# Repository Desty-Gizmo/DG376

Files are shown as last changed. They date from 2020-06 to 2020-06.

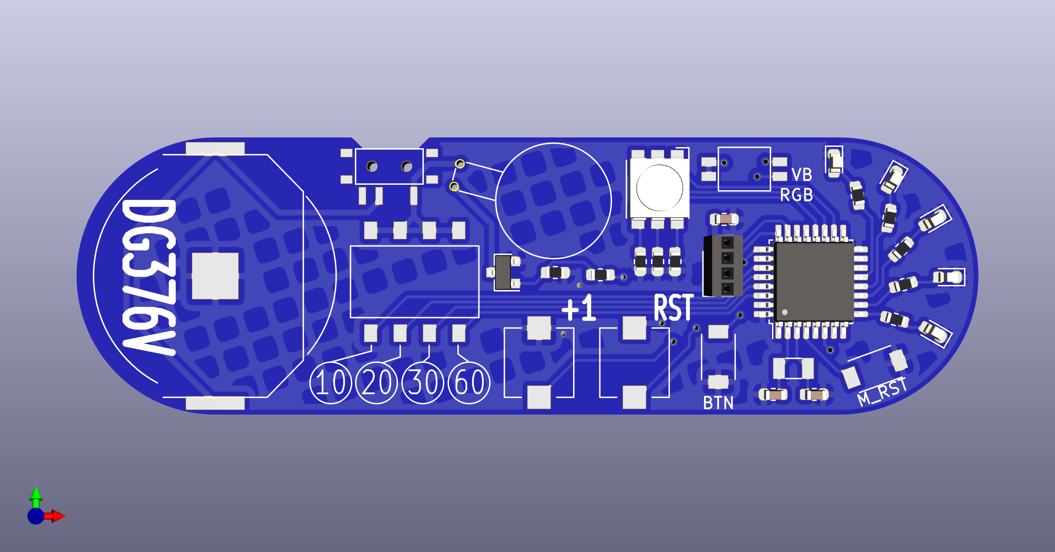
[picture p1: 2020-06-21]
Hardware/DG376_KiCad_F.png

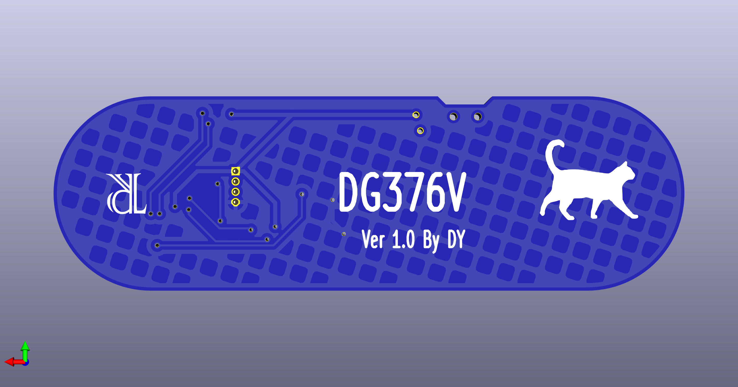
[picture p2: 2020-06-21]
Hardware/DG376_KiCad_B.png

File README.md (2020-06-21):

# DG376

DG means "Desty Gizmo" or "Desty Gadget", a series of low power gadgets.

376: a random number I assign to name the model.

DG376V: using 10mm disk vibration motor (through-hole).
DG376R: using biased weight vibration motor (SMD).

# Counter

A counter that supports quick countdown function. Will notify the user when the time is up.

# MCU

STM32L010C6T6 $1.70 -> $1.67.  
STM32L011K4T6 $1.79 -> $1.68. Has symbol in KiCad

# Note

- Set GPIO to float before sleep.
-

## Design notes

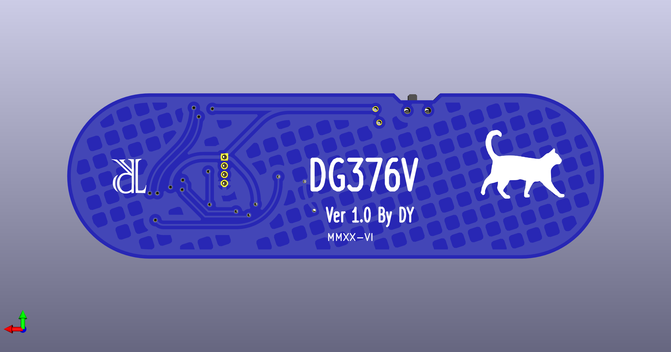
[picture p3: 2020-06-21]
Hardware/DG376_KiCad_B_2.png

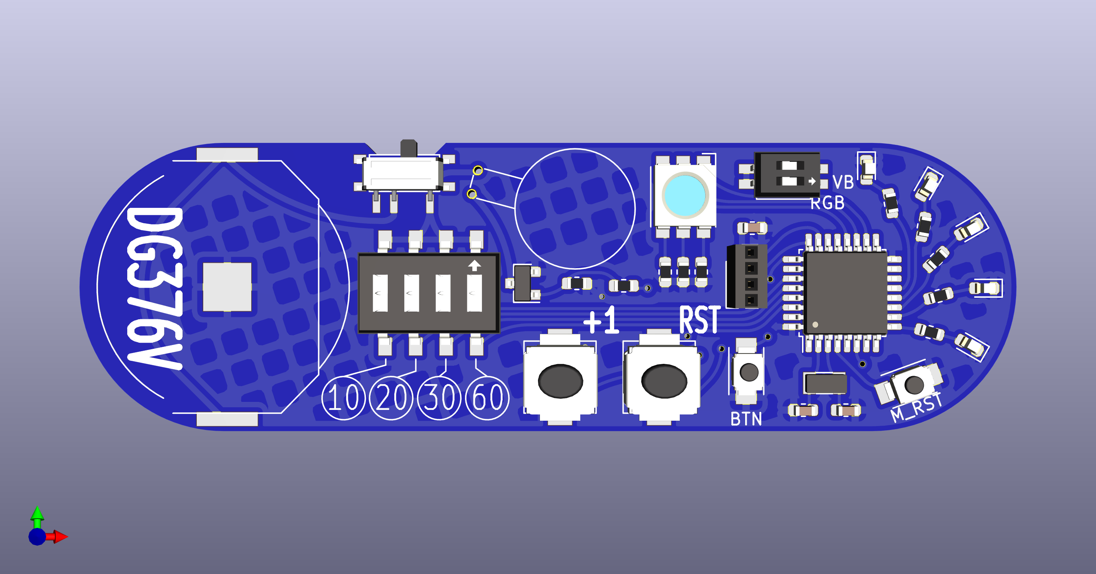
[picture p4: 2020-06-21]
Hardware/DG376_KiCad_F_2.png

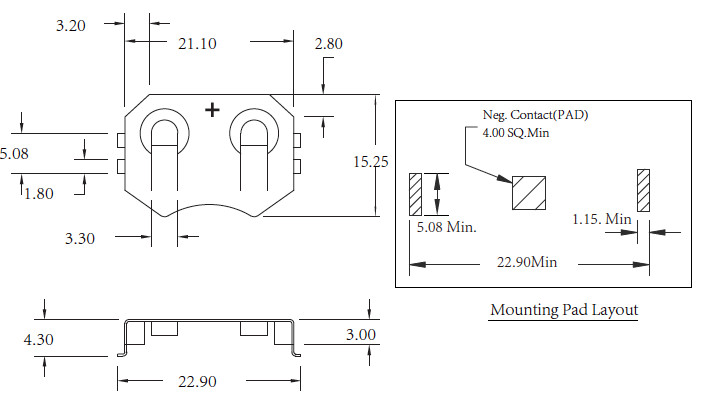
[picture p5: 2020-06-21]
Datasheet/CR2032 Battery Holder.jpg

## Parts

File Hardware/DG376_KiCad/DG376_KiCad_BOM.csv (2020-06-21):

Source: | /Users/dlyang/Dropbox/Project/2020.DG376-Counter/Hardware/DG376_KiCad/DG376_KiCad.kicad_sch
Date: | Friday, June 05, 2020 at 02:58:03 PM
Tool: | Eeschema (5.99.0-1734-g575ad7128)
Generator: | /private/var/folders/nt/y2zl667d17z2_5mz2jj_qz8r0000gn/T/AppTranslocation/0FF80091-CBEB-471F-9E27-5001AB55A9E2/d/kicad.app/Contents/SharedSupport/plugins/bom_csv_grouped_by_value.py
Component Count: | 32
Individual Components:
Item | Qty | Reference(s) | Value | LibPart | Footprint | Datasheet
 |  | BT1 | CR2032 | Device:Battery_Cell | LTD_Customized:CR2032_Battery_Holder | ~
 |  | C1 | 12pF | Device:C_Small | Capacitor_SMD:C_0603_1608Metric | ~
 |  | C2 | 12pF | Device:C_Small | Capacitor_SMD:C_0603_1608Metric | ~
 |  | C3 | 10nF | Device:C_Small | Capacitor_SMD:C_0603_1608Metric | ~
 |  | D1 | RGB_LED_5050 | DLY_Customized:RGB_LED_5050 | LED_SMD:LED_RGB_5050-6
 |  | D2 | LED | Device:LED | LED_SMD:LED_0603_1608Metric | ~
 |  | D3 | LED | Device:LED | LED_SMD:LED_0603_1608Metric | ~
 |  | D4 | LED | Device:LED | LED_SMD:LED_0603_1608Metric | ~
 |  | D5 | LED | Device:LED | LED_SMD:LED_0603_1608Metric | ~
 |  | D6 | LED | Device:LED | LED_SMD:LED_0603_1608Metric | ~
 |  | J1 | Conn_01x04 | Connector_Generic:Conn_01x04 | Connector_PinSocket_1.27mm:PinSocket_1x04_P1.27mm_Vertical | ~
 |  | M1 | Motor_DC | Motor:Motor_DC | LTD_Customized:Vibration Motor 10mm | ~
 |  | Q1 | MMBT3904 | Transistor_BJT:MMBT3904 | Package_TO_SOT_SMD:SOT-23 | https://www.fairchildsemi.com/datasheets/2N/2N3904.pdf
 |  | R3 | 2.2k | Device:R | Resistor_SMD:R_0603_1608Metric | ~
 |  | R4 | 2.2k | Device:R | Resistor_SMD:R_0603_1608Metric | ~
 |  | R5 | 2.2k | Device:R | Resistor_SMD:R_0603_1608Metric | ~
 |  | R6 | 2.2k | Device:R | Resistor_SMD:R_0603_1608Metric | ~
 |  | R7 | 2.2k | Device:R | Resistor_SMD:R_0603_1608Metric | ~
 |  | R8 | 2.2k | Device:R | Resistor_SMD:R_0603_1608Metric | ~
 |  | R9 | 2.2k | Device:R | Resistor_SMD:R_0603_1608Metric | ~
 |  | R10 | 2.2k | Device:R | Resistor_SMD:R_0603_1608Metric | ~
 |  | R11 | 4.7k | Device:R | Resistor_SMD:R_0603_1608Metric | ~
 |  | R12 | 47k | Device:R | Resistor_SMD:R_0603_1608Metric | ~
 |  | SW1 | PWR_SW | Switch:SW_SPDT | LTD_Customized:Shouhan MSK12C02 | ~
 |  | SW2 | CNT_START | Switch:SW_Push | LTD_Customized:Alps_SMD_Button_SKPMAPE010 | ~
 |  | SW3 | T_SELECT | Switch:SW_DIP_x04 | LTD_Customized:Diptronics DMR-04-V-TR | ~
 |  | SW4 | CNT_RST | Switch:SW_Push | LTD_Customized:Alps_SMD_Button_SKPMAPE010 | ~
 |  | SW5 | MCU_RST | Switch:SW_Push | LTD_Customized:USAKRO UK-B0273-SP25Y | ~
 |  | SW6 | USR_BTN | Switch:SW_Push | LTD_Customized:USAKRO UK-B0273-SP25Y | ~
 |  | SW7 | SW_DIP_x02 | Switch:SW_DIP_x02 | LTD_Customized:Diptronics_SW_DIP_DHN-02-V-T-R | ~
 |  | U1 | STM32L011K4Tx | MCU_ST_STM32L0:STM32L011K4Tx | Package_QFP:LQFP-32_7x7mm_P0.8mm | http://www.st.com/st-web-ui/static/active/en/resource/technical/document/datasheet/DM00206508.pdf
 |  | Y1 | 32.768Hz_OSC | Device:Crystal | Crystal:Crystal_SMD_3215-2Pin_3.2x1.5mm | ~
Collated Components:
Item | Qty | Reference(s) | Value | LibPart | Footprint | Datasheet
1 | 1 | BT1 | CR2032 | Device:Battery_Cell | LTD_Customized:CR2032_Battery_Holder | ~
2 | 2 | C1, C2 | 12pF | Device:C_Small | Capacitor_SMD:C_0603_1608Metric | ~
3 | 1 | C3 | 10nF | Device:C_Small | Capacitor_SMD:C_0603_1608Metric | ~
4 | 1 | D1 | RGB_LED_5050 | DLY_Customized:RGB_LED_5050 | LED_SMD:LED_RGB_5050-6
5 | 5 | D2, D3, D4, D5, D6 | LED | Device:LED | LED_SMD:LED_0603_1608Metric | ~
6 | 1 | J1 | Conn_01x04 | Connector_Generic:Conn_01x04 | Connector_PinSocket_1.27mm:PinSocket_1x04_P1.27mm_Vertical | ~
7 | 1 | M1 | Motor_DC | Motor:Motor_DC | LTD_Customized:Vibration Motor 10mm | ~
8 | 1 | Q1 | MMBT3904 | Transistor_BJT:MMBT3904 | Package_TO_SOT_SMD:SOT-23 | https://www.fairchildsemi.com/datasheets/2N/2N3904.pdf
9 | 8 | R3, R4, R5, R6, R7, R8, R9, R10 | 2.2k | Device:R | Resistor_SMD:R_0603_1608Metric | ~
10 | 1 | R11 | 4.7k | Device:R | Resistor_SMD:R_0603_1608Metric | ~
11 | 1 | R12 | 47k | Device:R | Resistor_SMD:R_0603_1608Metric | ~
12 | 1 | SW1 | PWR_SW | Switch:SW_SPDT | LTD_Customized:Shouhan MSK12C02 | ~
13 | 1 | SW2 | CNT_START | Switch:SW_Push | LTD_Customized:Alps_SMD_Button_SKPMAPE010 | ~
14 | 1 | SW3 | T_SELECT | Switch:SW_DIP_x04 | LTD_Customized:Diptronics DMR-04-V-TR | ~
15 | 1 | SW4 | CNT_RST | Switch:SW_Push | LTD_Customized:Alps_SMD_Button_SKPMAPE010 | ~
16 | 1 | SW5 | MCU_RST | Switch:SW_Push | LTD_Customized:USAKRO UK-B0273-SP25Y | ~
17 | 1 | SW6 | USR_BTN | Switch:SW_Push | LTD_Customized:USAKRO UK-B0273-SP25Y | ~
18 | 1 | SW7 | SW_DIP_x02 | Switch:SW_DIP_x02 | LTD_Customized:Diptronics_SW_DIP_DHN-02-V-T-R | ~
19 | 1 | U1 | STM32L011K4Tx | MCU_ST_STM32L0:STM32L011K4Tx | Package_QFP:LQFP-32_7x7mm_P0.8mm | http://www.st.com/st-web-ui/static/active/en/resource/technical/document/datasheet/DM00206508.pdf
20 | 1 | Y1 | 32.768Hz_OSC | Device:Crystal | Crystal:Crystal_SMD_3215-2Pin_3.2x1.5mm | ~

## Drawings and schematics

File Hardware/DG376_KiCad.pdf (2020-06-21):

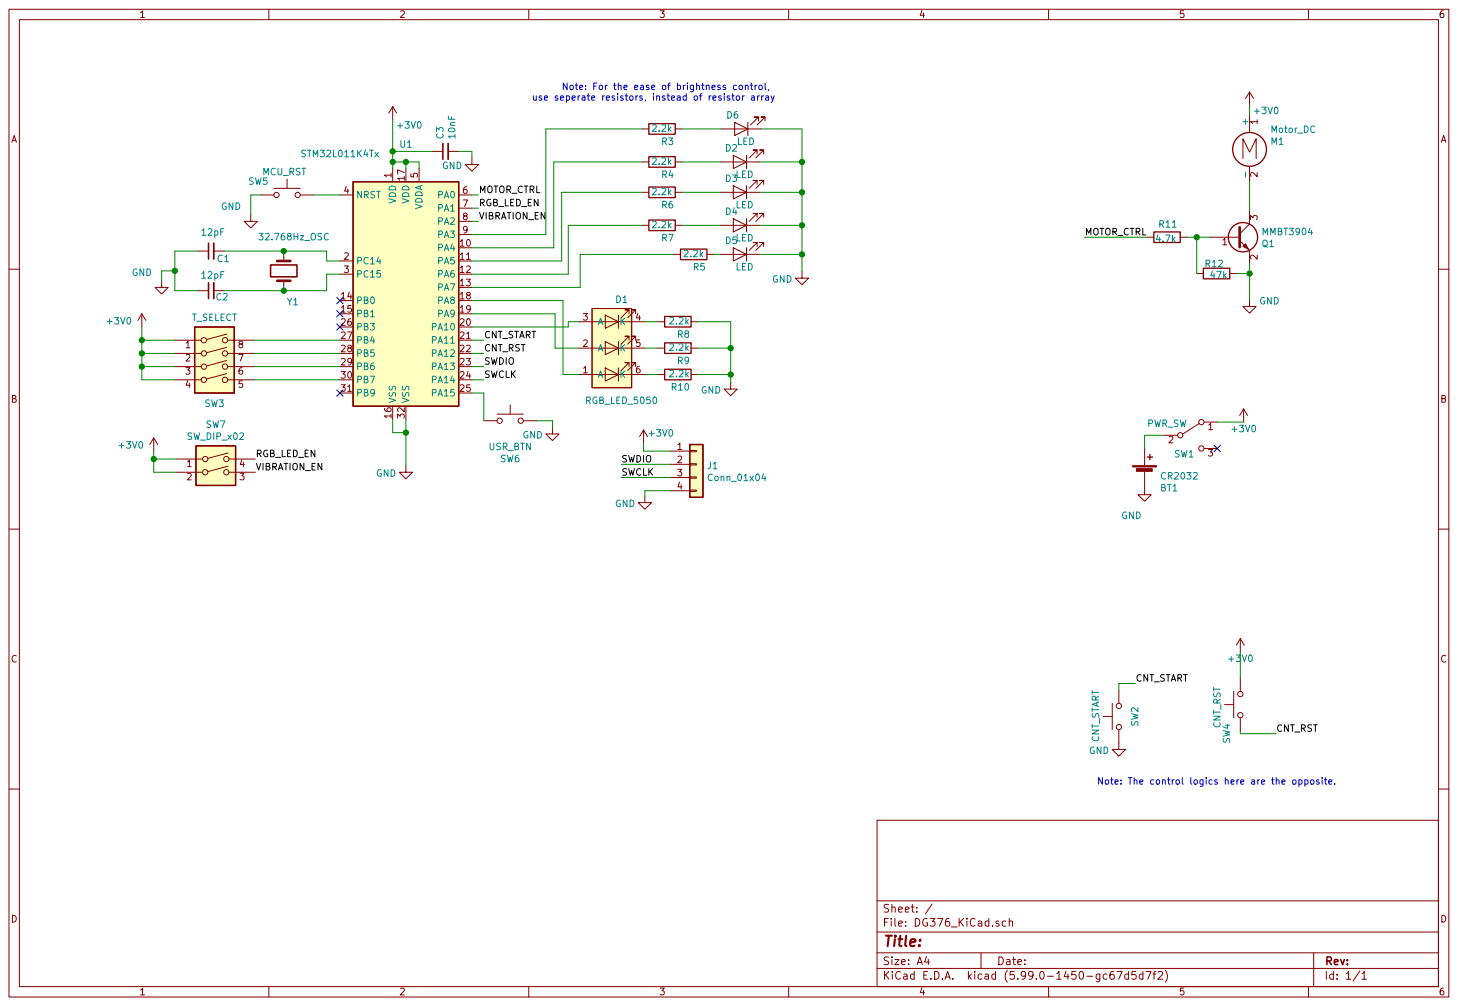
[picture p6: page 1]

SWCLK Note: For the ease of brightness control,
use seperate resistors, instead of resistor array
RGB_LED_EN MOTOR_CTRL SWCLK

Note: The control logics here are the opposite.

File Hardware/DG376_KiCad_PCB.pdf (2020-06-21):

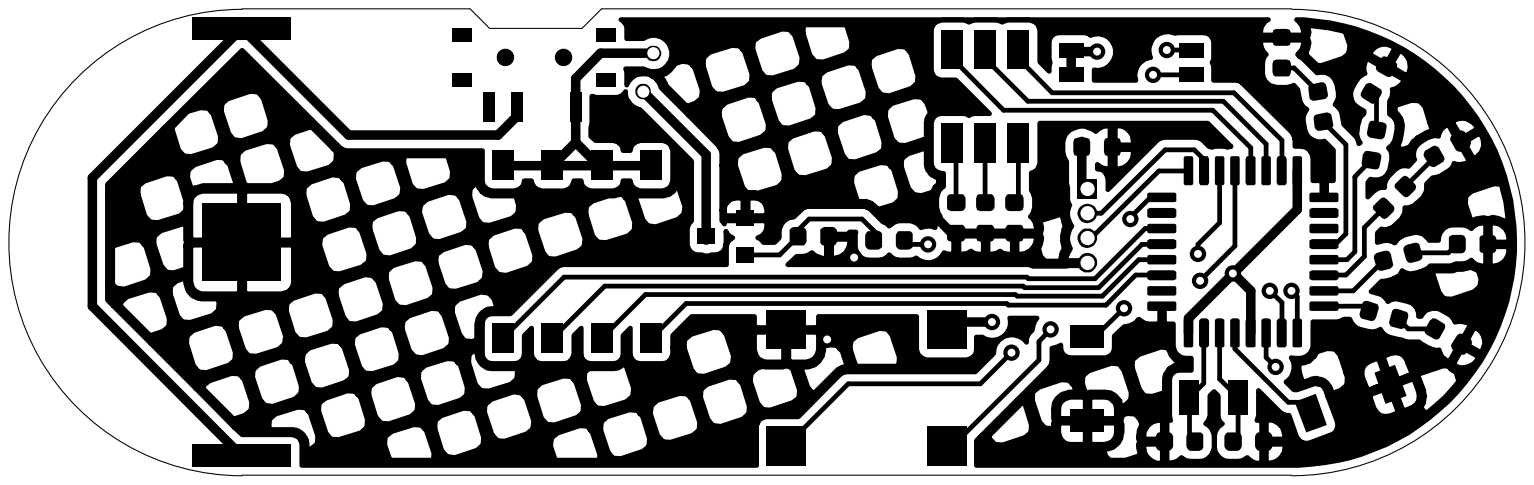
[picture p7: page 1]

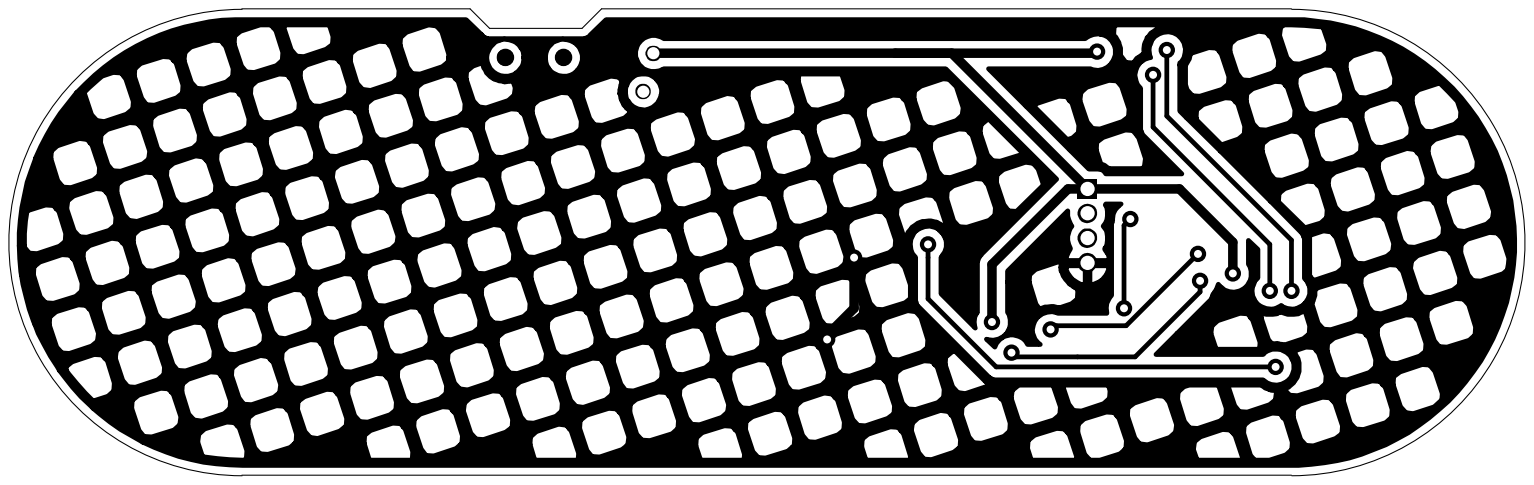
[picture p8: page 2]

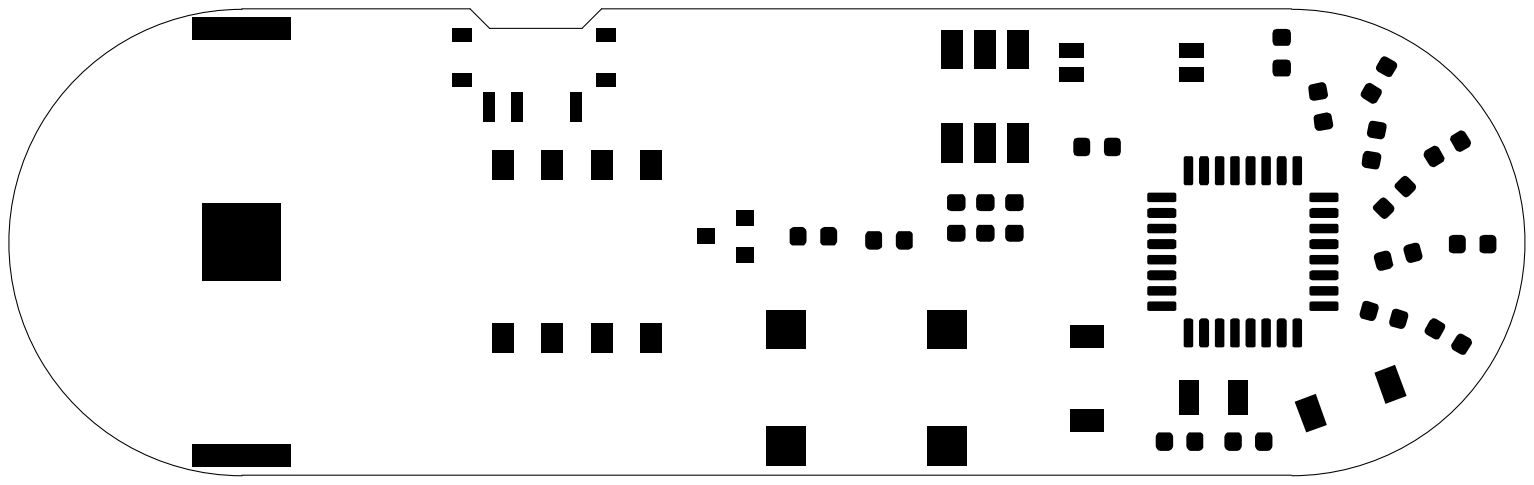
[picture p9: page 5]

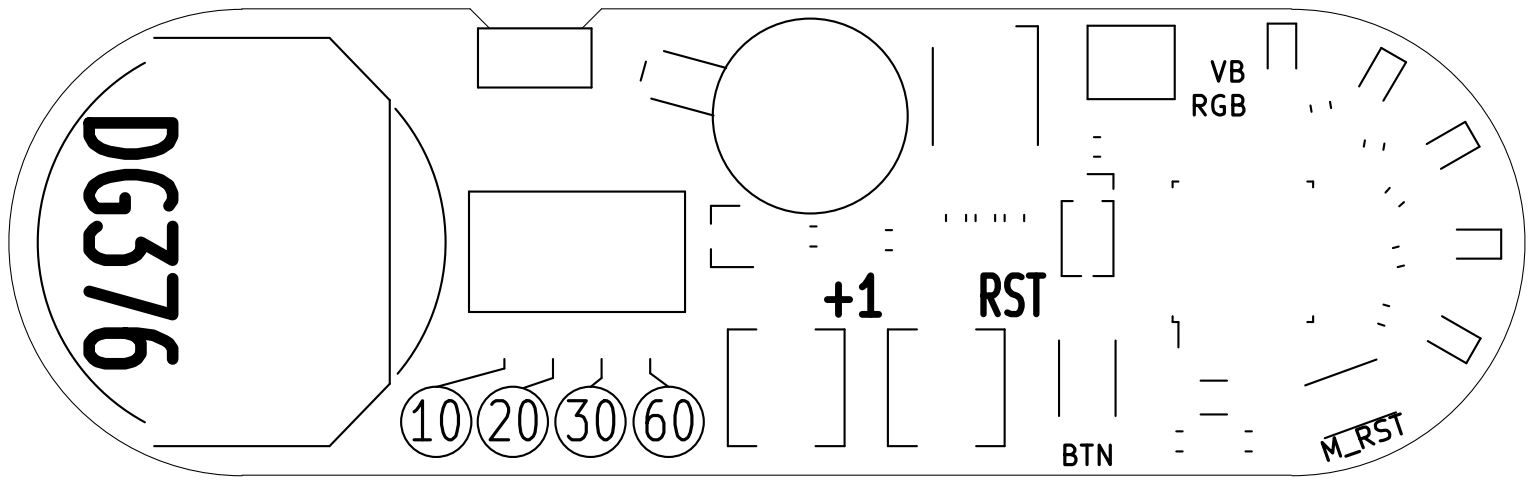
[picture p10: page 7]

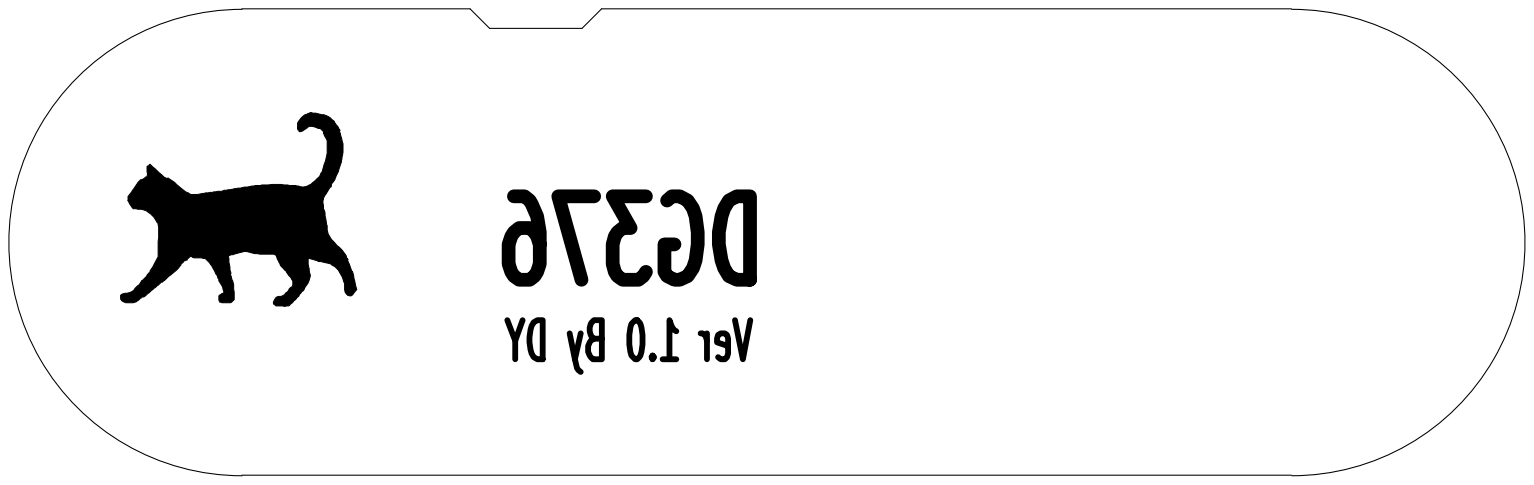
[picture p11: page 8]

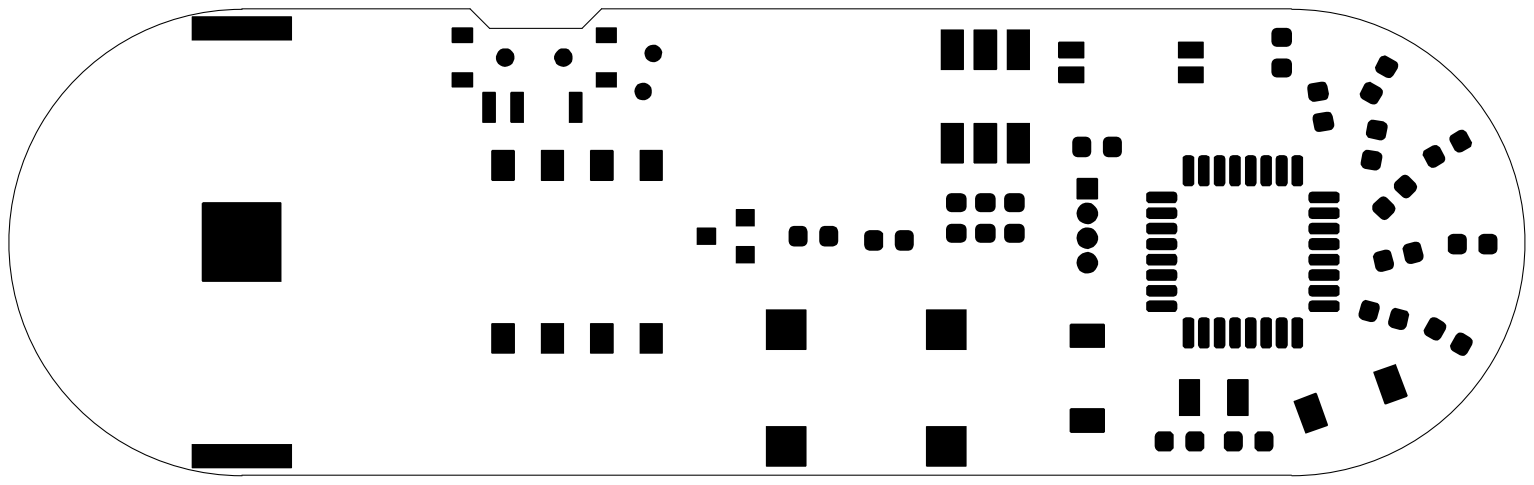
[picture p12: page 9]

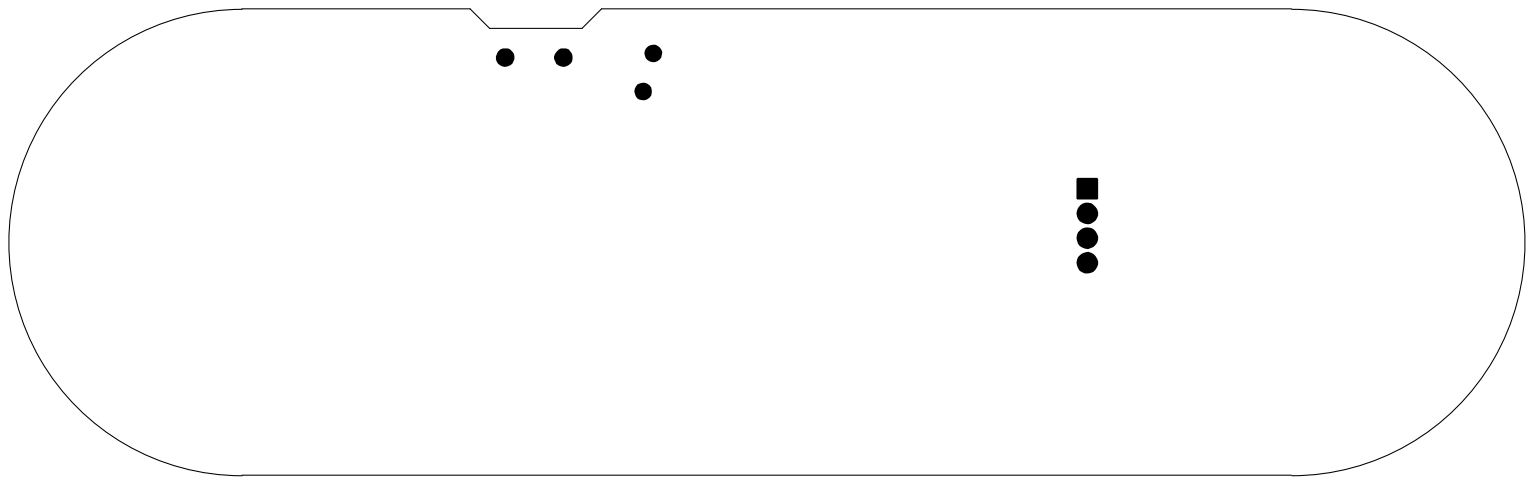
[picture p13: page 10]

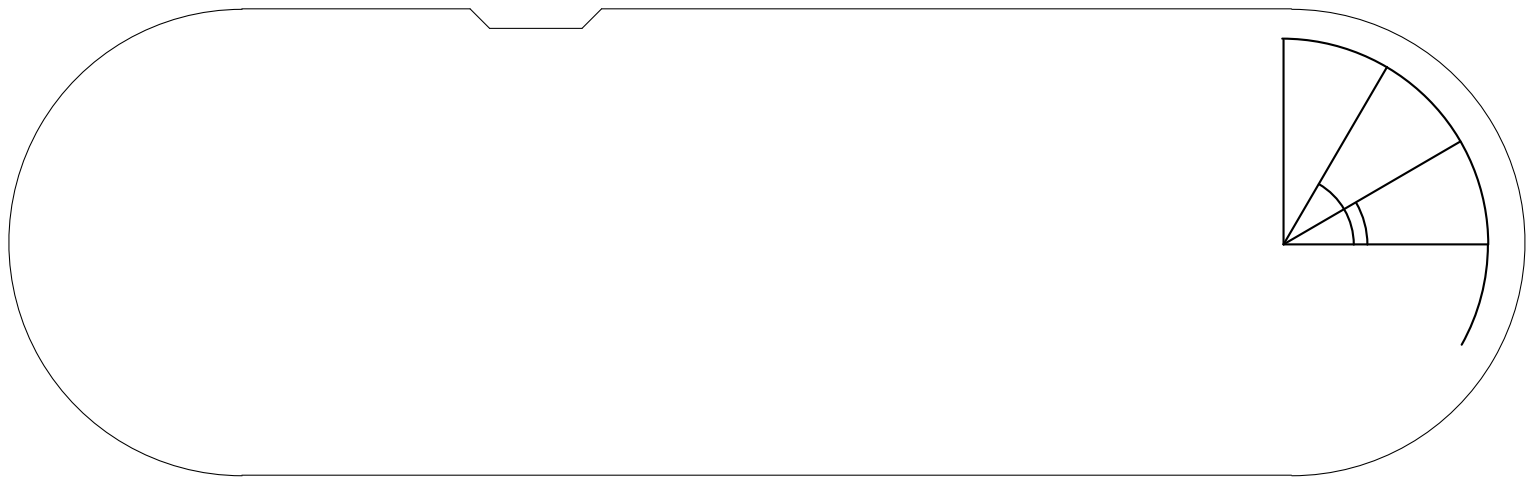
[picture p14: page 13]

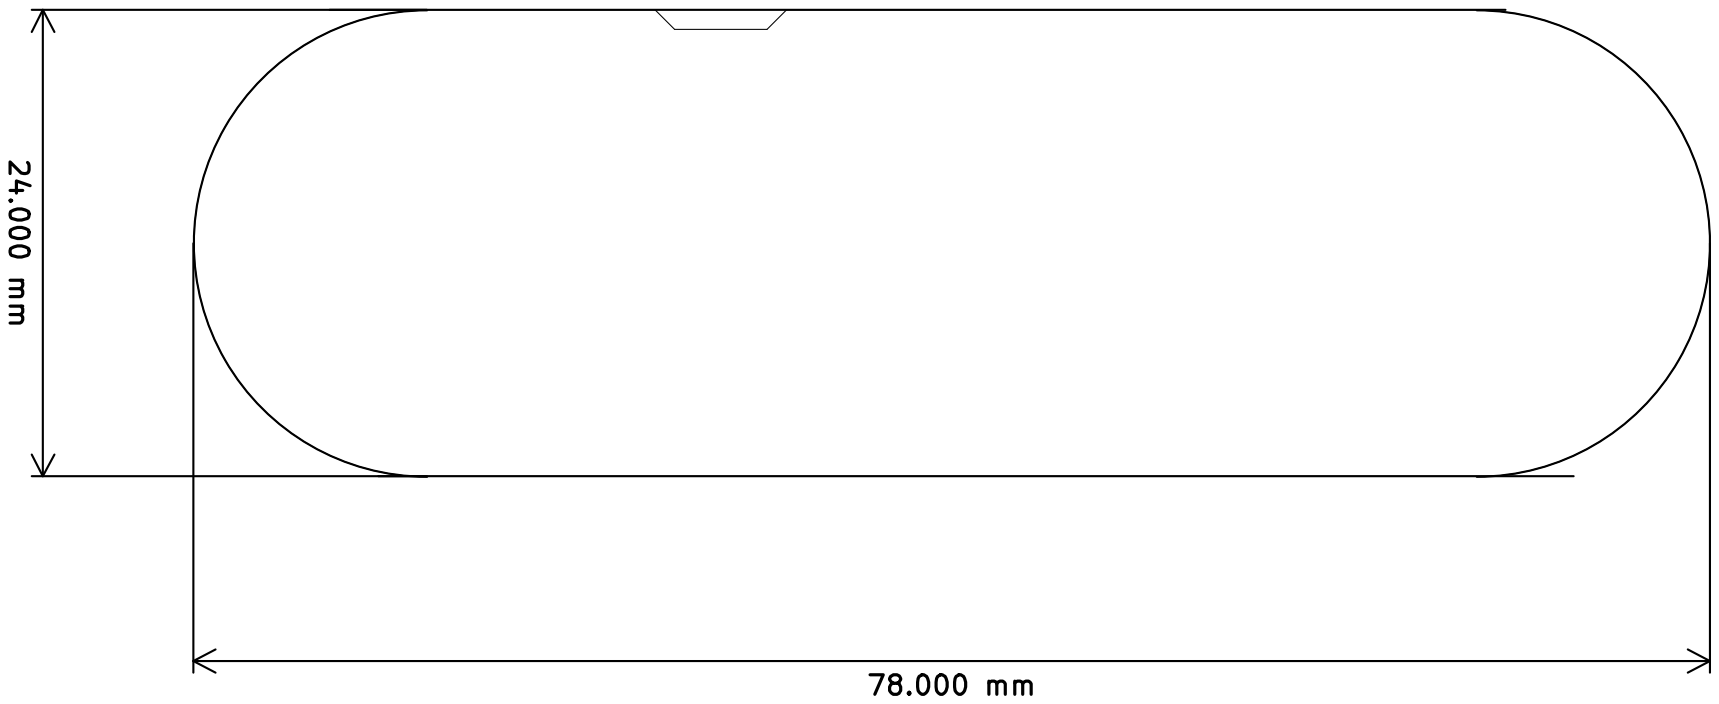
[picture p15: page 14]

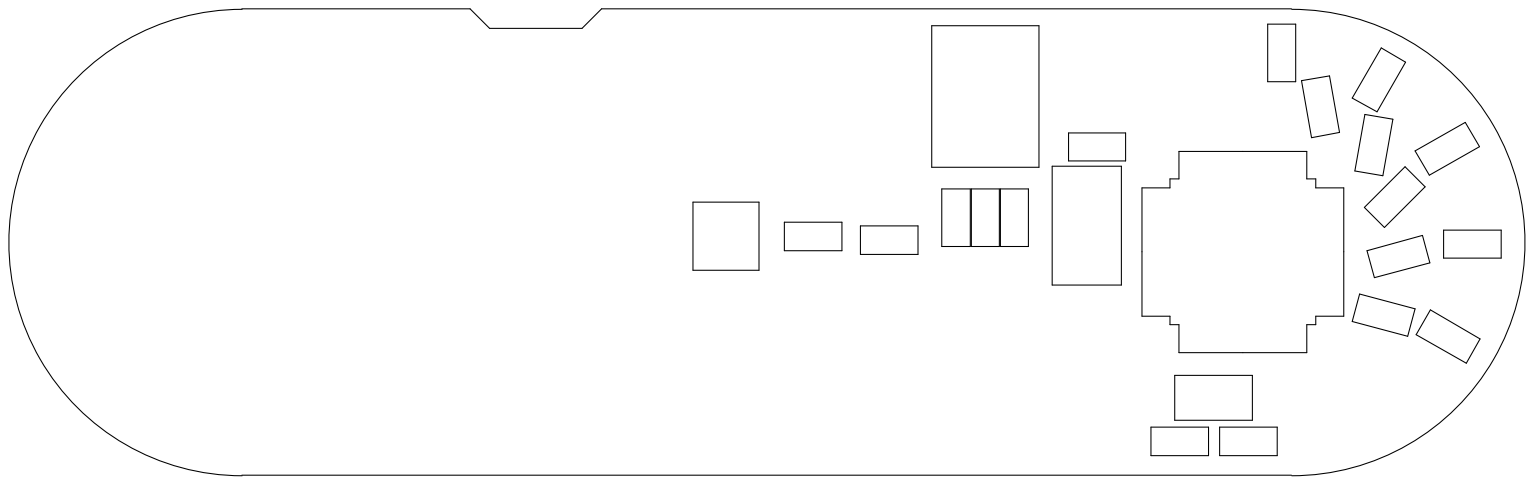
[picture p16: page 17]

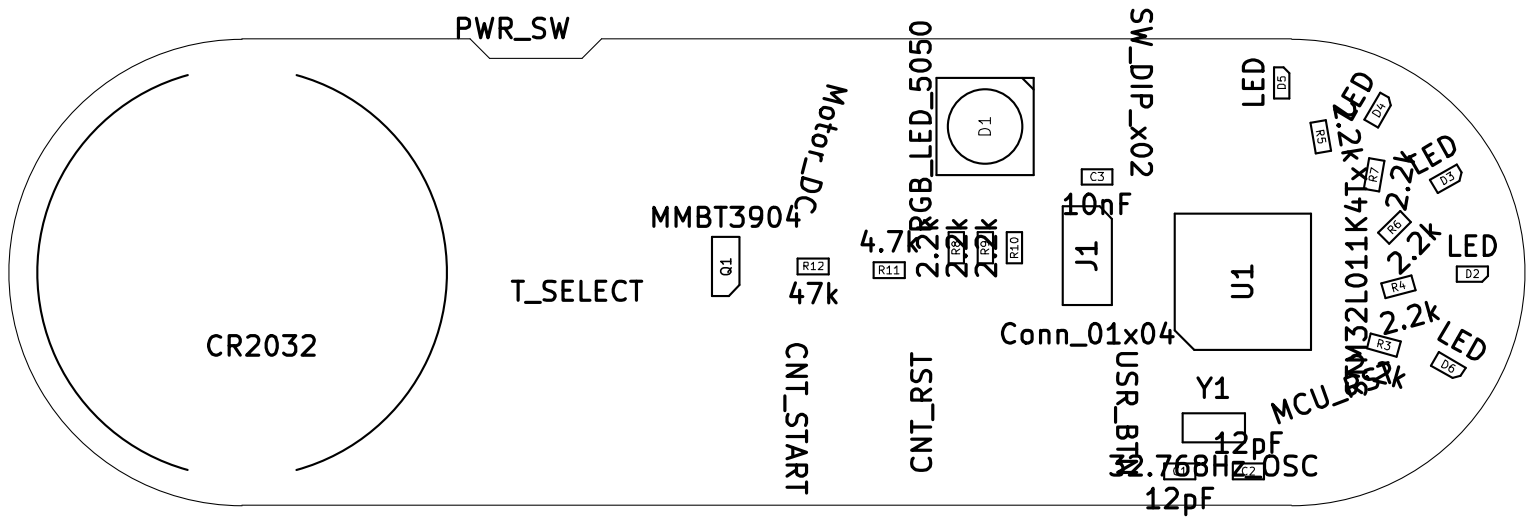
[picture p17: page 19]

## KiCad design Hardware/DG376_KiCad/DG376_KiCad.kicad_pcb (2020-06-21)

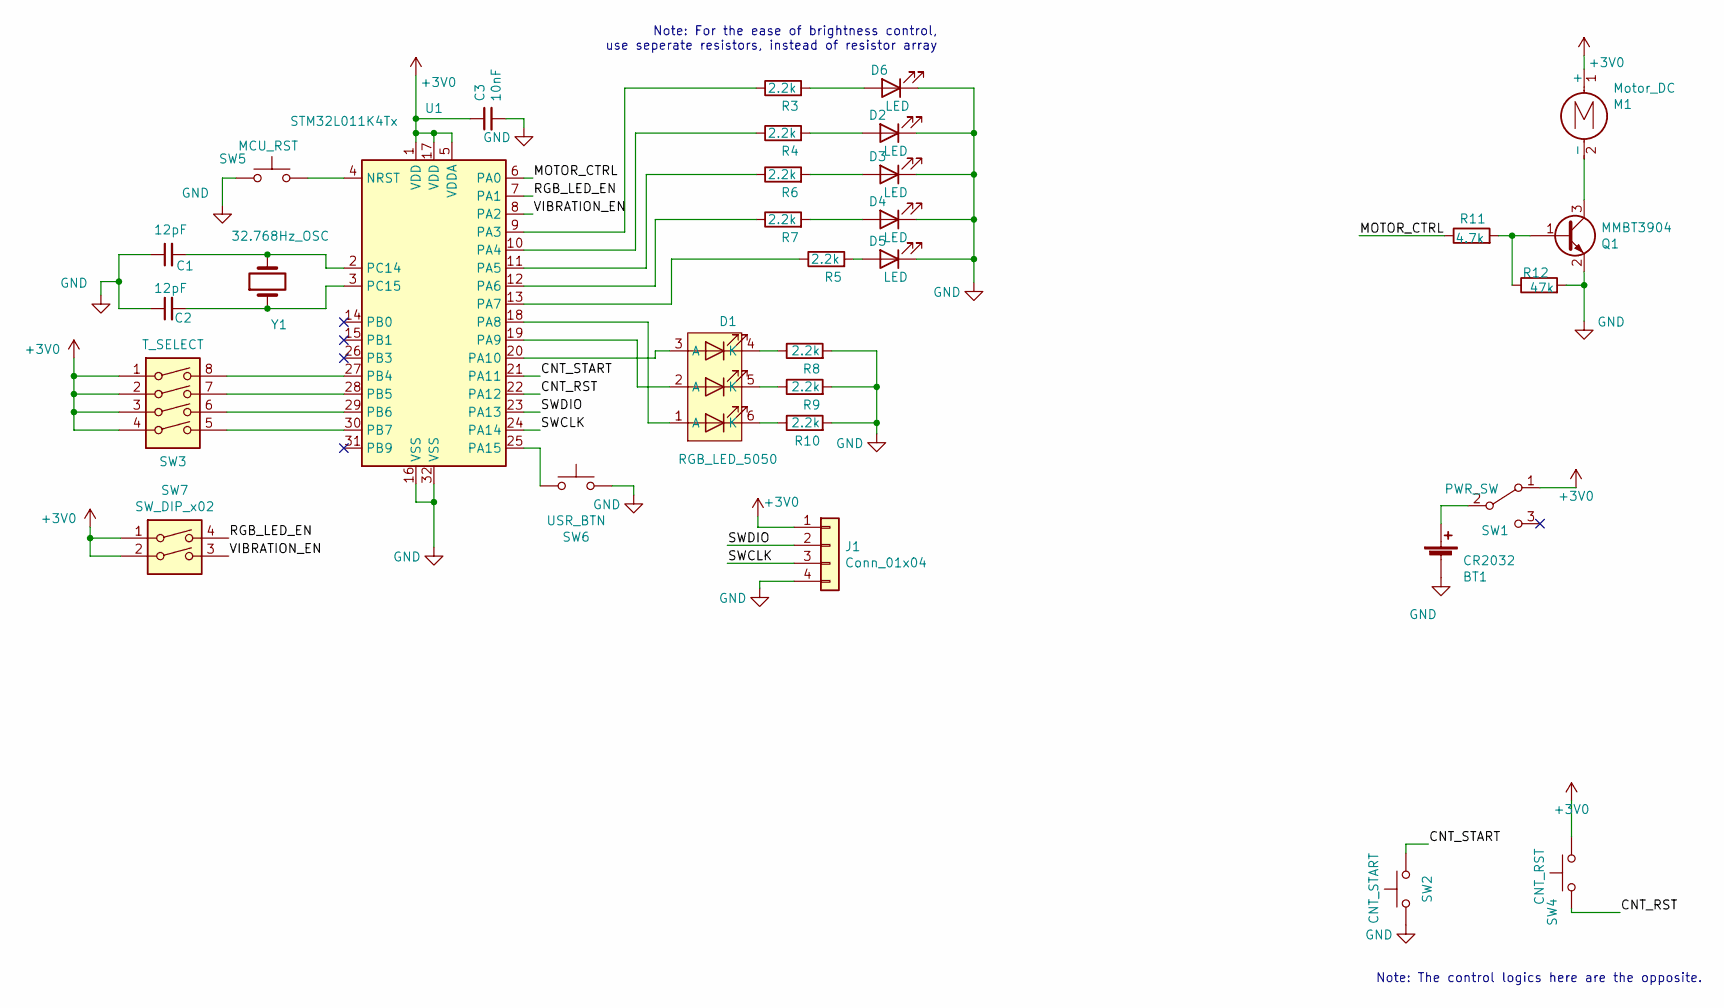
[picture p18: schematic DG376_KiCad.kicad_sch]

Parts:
BT1: CR2032; CR2032_Battery_Holder
C1, C2: 12pF; C_0603_1608Metric
C3: 10nF; C_0603_1608Metric
D1: RGB_LED_5050; LED_RGB_5050-6
D2, D3, D4, D5, D6: LED; LED_0603_1608Metric
J1: Conn_01x04; PinSocket_1x04_P1.27mm_Vertical
M1: Motor_DC; Vibration Motor 10mm
Q1: MMBT3904; SOT-23
R3, R4, R5, R6, R7, R8, R9, R10: 2.2k; R_0603_1608Metric
R11: 4.7k; R_0603_1608Metric
R12: 47k; R_0603_1608Metric
SW1: PWR_SW; Shouhan MSK12C02
SW2: CNT_START; Alps_SMD_Button_SKPMAPE010
SW3: T_SELECT; Diptronics DMR-04-V-TR
SW4: CNT_RST; Alps_SMD_Button_SKPMAPE010
SW5: MCU_RST; USAKRO UK-B0273-SP25Y
SW6: USR_BTN; USAKRO UK-B0273-SP25Y
SW7: SW_DIP_x02; Diptronics_SW_DIP_DHN-02-V-T-R
U1: STM32L011K4Tx; LQFP-32_7x7mm_P0.8mm
Y1: 32.768Hz_OSC; Crystal_SMD_3215-2Pin_3.2x1.5mm

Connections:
+3V0: C3.1, J1.1, M1.1 (+), SW1.1 (A), SW3.1, SW3.2, SW3.3, SW3.4, SW4.2, SW7.1, SW7.2, U1.1 (VDD), U1.5 (VDDA), U1.17 (VDD)
/CNT_RST: SW4.1, U1.22 (PA12)
/CNT_START: SW2.2, U1.21 (PA11)
/MOTOR_CTRL: R11.1, U1.6 (PA0)
/RGB_LED_EN: SW7.4, U1.7 (PA1)
/SWCLK: J1.3, U1.24 (PA14)
/SWDIO: J1.2, U1.23 (PA13)
/VIBRATION_EN: SW7.3, U1.8 (PA2)
GND: BT1.2 (-), C1.1, C2.1, C3.2, D2.1 (K), D3.1 (K), D4.1 (K), D5.1 (K), D6.1 (K), J1.4, Q1.2 (E), R8.2, R9.2, R10.2, R12.2, SW2.1, SW5.1, SW6.2, U1.16 (VSS), U1.32 (VSS)
unnamed: BT1.1 (+), SW1.2 (B)
unnamed: C1.2, U1.2 (PC14), Y1.2
unnamed: C2.2, U1.3 (PC15), Y1.1
unnamed: D1.1 (A), U1.18 (PA8)
unnamed: D1.2 (A), U1.19 (PA9)
unnamed: D1.3 (A), U1.20 (PA10)
unnamed: D1.4 (K), R8.1
unnamed: D1.5 (K), R9.1
unnamed: D1.6 (K), R10.1
unnamed: D2.2 (A), R4.2
unnamed: D3.2 (A), R6.2
unnamed: D4.2 (A), R7.2
unnamed: D5.2 (A), R5.2
unnamed: D6.2 (A), R3.2
unnamed: M1.2 (-), Q1.3 (C)
unnamed: Q1.1 (B), R11.2, R12.1
unnamed: R3.1, U1.9 (PA3)
unnamed: R4.1, U1.10 (PA4)
unnamed: R5.1, U1.13 (PA7)
unnamed: R6.1, U1.11 (PA5)
unnamed: R7.1, U1.12 (PA6)
unnamed: SW3.5, U1.30 (PB7)
unnamed: SW3.6, U1.29 (PB6)
unnamed: SW3.7, U1.28 (PB5)
unnamed: SW3.8, U1.27 (PB4)
unnamed: SW5.2, U1.4 (NRST)
unnamed: SW6.1, U1.25 (PA15)

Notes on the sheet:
Note: For the ease of brightness control, use seperate resistors, instead of resistor array
Note: The control logics here are the opposite.

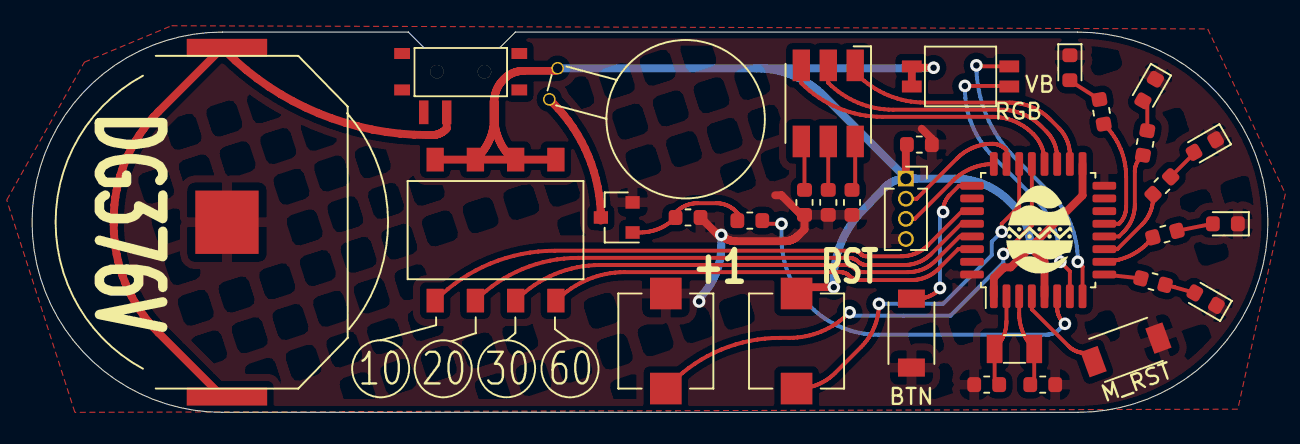
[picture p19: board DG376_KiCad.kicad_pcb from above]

Board: 2 copper layers, 78.0 x 24.0 mm, 32 parts (0 on the bottom side), 36 nets.

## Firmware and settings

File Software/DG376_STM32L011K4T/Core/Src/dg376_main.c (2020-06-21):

/**
   @file dg376_main.c
   @brief Actual main program body
   @author LanternD
   @date_created 2020.06.20
   @note The main.c is always subject to modification by the CubeMX code
   generator. I would like to move the user added functions here to keep all my
   code consistent.
 */

#include "dg376_main.h"
#include "main.h"

/* Global variables **********************************************************/
timer_choice_t g_timer_choice_st = {0, 0, 0, 0};
notification_choice_t g_notification_st = {0, 0};
dg376_status_et g_dg376_status = STATE_IDLE;

int16_t remain_timer = 0;
uint8_t led_on_count = 0; // 0 - 5

/* Functions *****************************************************************/
void HAL_GPIO_EXTI_Callback(uint16_t GPIO_Pin) {
  if (GPIO_Pin == CNT_START_Pin) {
    g_dg376_status = STATE_TIMER_ON;
    read_timer_choice(&g_timer_choice_st);
    remain_timer += calculate_incremental_step(g_timer_choice_st);
    if (led_on_count < 5){
      led_on_count += 1;
      turn_on_led_based_on_count();
    }

  } else if (GPIO_Pin == CNT_RST_Pin) {
    g_dg376_status = STATE_IDLE;
    // Switch to IDLE no matter what previous status is.
    switch (g_dg376_status) {
    case STATE_NOTIFYING:
      // Placeholder
      break;
    case STATE_TIMER_ON:
      turn_off_all_led();
      led_on_count = 0;
      remain_timer = 0;
      break;
    default:
      // Placeholder
      break;
    }
  }
}

void read_timer_choice(timer_choice_t *g_timer_st) {
  g_timer_st->s_10_enable =
      HAL_GPIO_ReadPin(S_10_SELECT_GPIO_Port, S_10_SELECT_Pin);
  g_timer_st->s_20_enable =
      HAL_GPIO_ReadPin(S_20_SELECT_GPIO_Port, S_20_SELECT_Pin);
  g_timer_st->s_30_enable =
      HAL_GPIO_ReadPin(S_30_SELECT_GPIO_Port, S_30_SELECT_Pin);
  g_timer_st->s_60_enable =
      HAL_GPIO_ReadPin(S_60_SELECT_GPIO_Port, S_60_SELECT_Pin);
}

void read_notification_choice(notification_choice_t *g_notification_st) {
  g_notification_st->rgb_enable =
      HAL_GPIO_ReadPin(RGB_LED_EN_GPIO_Port, RGB_LED_EN_Pin);
  g_notification_st->vibration_enable =
      HAL_GPIO_ReadPin(VIBRATION_EN_GPIO_Port, VIBRATION_EN_Pin);
}

uint8_t calulate_incremental_step(timer_choice_t *g_timer_choice_st) {
  uint8_t res = 0;
  res += 10 * g_timer_choice_st->s_10_enable +
         20 * g_timer_choice_st->s_20_enable +
         30 * g_timer_choice_st->s_30_enable +
         60 * g_timer_choice_st->s_60_enable;
  if (res == 0) {
    return 1;
  } else {
    return res;
  }
}

void turn_off_all_led(void) {
  LED0_OFF;
  LED1_OFF;
  LED2_OFF;
  LED3_OFF;
  LED4_OFF;
}

void turn_on_led_based_on_count(void) {
  turn_off_all_led();
  switch (led_on_count) {
  case 0:
    break;
  case 1:
    LED0_ON;
    break;
  case 2:
    LED0_ON;
    LED1_ON;
    break;
  case 3:
    LED0_ON;
    LED1_ON;
    LED2_ON;
    break;
  case 4:
    LED0_ON;
    LED1_ON;
    LED2_ON;
    LED3_ON;
    break;
  case 5:
    LED0_ON;
    LED1_ON;
    LED2_ON;
    LED3_ON;
    LED4_ON;
    break;
  default:
    break;
  }
}

void start_notification(void) {
  read_notification_choice(&g_notification_st);
  uint8_t notification_cycle_count = 0;
  if (g_notification_st.rgb_enable == 0 &&
      g_notification_st.vibration_enable == 0) {
    // Use LED Blinking to notify the user.
    LED0_ON;
    LED1_OFF;
    LED2_ON;
    LED3_OFF;
    LED4_ON;
    while (g_dg376_status == STATE_NOTIFYING && notification_cycle_count < 40) {
      LED0_TOGGLE;
      LED1_TOGGLE;
      LED2_TOGGLE;
      LED3_TOGGLE;
      LED4_TOGGLE;
      HAL_Delay(250);
      notification_cycle_count += 1;
    }
    turn_off_all_led();
  } else {
    while (g_dg376_status == STATE_NOTIFYING && notification_cycle_count < 10) {
      if (g_notification_st.rgb_enable) {
        LED_R_ON;
        LED_G_OFF;
        LED_B_OFF;
        HAL_Delay(200);
        LED_R_OFF;
        LED_G_ON;
        LED_B_OFF;
        HAL_Delay(200);
        LED_R_OFF;
        LED_G_OFF;
        LED_B_ON;
        HAL_Delay(200);
      }
      if (g_notification_st.vibration_enable) {
        MOTOR_ON;
        HAL_Delay(400);
        MOTOR_OFF;
      }
      notification_cycle_count += 1;
    }
  }
  g_dg376_status = STATE_IDLE;
}

void timer_expired(void){
  g_dg376_status = STATE_NOTIFYING;
  start_notification();
}

void dg376_while_loop(void){
  while (1) {
    if (g_dg376_status == STATE_TIMER_ON){
      HAL_Delay(1000);
      remain_timer -= 1;
      if (remain_timer <= 0){
        timer_expired();
      }
    }
  }
}

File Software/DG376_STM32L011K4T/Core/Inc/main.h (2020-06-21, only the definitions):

#define MOTOR_CTRL_Pin GPIO_PIN_0
#define MOTOR_CTRL_GPIO_Port GPIOA
#define RGB_LED_EN_Pin GPIO_PIN_1
#define RGB_LED_EN_GPIO_Port GPIOA
#define VIBRATION_EN_Pin GPIO_PIN_2
#define VIBRATION_EN_GPIO_Port GPIOA
#define LED_0_Pin GPIO_PIN_3
#define LED_0_GPIO_Port GPIOA
#define LED_1_Pin GPIO_PIN_4
#define LED_1_GPIO_Port GPIOA
#define LED_2_Pin GPIO_PIN_5
#define LED_2_GPIO_Port GPIOA
#define LED_3_Pin GPIO_PIN_6
#define LED_3_GPIO_Port GPIOA
#define LED_4_Pin GPIO_PIN_7
#define LED_4_GPIO_Port GPIOA
#define LED_R_Pin GPIO_PIN_8
#define LED_R_GPIO_Port GPIOA
#define LED_G_Pin GPIO_PIN_9
#define LED_G_GPIO_Port GPIOA
#define LED_B_Pin GPIO_PIN_10
#define LED_B_GPIO_Port GPIOA
#define CNT_START_Pin GPIO_PIN_11
#define CNT_START_GPIO_Port GPIOA
#define CNT_RST_Pin GPIO_PIN_12
#define CNT_RST_GPIO_Port GPIOA
#define USR_BTN_Pin GPIO_PIN_15
#define USR_BTN_GPIO_Port GPIOA
#define S_10_SELECT_Pin GPIO_PIN_4
#define S_10_SELECT_GPIO_Port GPIOB
#define S_20_SELECT_Pin GPIO_PIN_5
#define S_20_SELECT_GPIO_Port GPIOB
#define S_30_SELECT_Pin GPIO_PIN_6
#define S_30_SELECT_GPIO_Port GPIOB
#define S_60_SELECT_Pin GPIO_PIN_7
#define S_60_SELECT_GPIO_Port GPIOB

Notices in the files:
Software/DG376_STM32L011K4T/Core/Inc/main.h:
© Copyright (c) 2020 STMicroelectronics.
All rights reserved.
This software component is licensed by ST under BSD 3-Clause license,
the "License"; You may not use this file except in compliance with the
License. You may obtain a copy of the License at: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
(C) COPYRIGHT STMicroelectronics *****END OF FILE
